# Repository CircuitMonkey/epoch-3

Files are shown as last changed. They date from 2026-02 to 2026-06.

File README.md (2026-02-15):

# epoch-3
Haptic Field Emitter using Vibration Motors

A follow on to [Epoch 2](https://github.com/CircuitMonkey/epoch-2) but in it's fifth generation.  Redesigned with [RaspberryPi Pico 2](https://www.raspberrypi.com/products/raspberry-pi-pico-2/) and a [4-inch TFT SPI resistive touch display](https://www.amazon.com/dp/B0CKRJ81B5).  Motors driven with [pca9685 PWM controller](https://learn.adafruit.com/adafruit-16-channel-pwm-servo-hat-for-raspberry-pi)/[Amazon PCA9685 Board](https://www.amazon.com/dp/B0D73811V8) and FET outputs in order to drive bigger motors. 

### Now 100% Python Free
Epoch-3 improves upon Epoch-2 by eliminating the use of Circuit Python, which ran extremely slow, cumbersome to program (no proper IDE) and caused many unexpected run-time errors. Epoch-3 uses proven Arduino C++ libraries and much easier to program/debug in for us old timers.

### Display Changes
The display has also been changed.  Epoch-2 used a IPS type display, and while it had more color rannge, it used nealy all the pins on the microcontroller and had slow update rates for most UI features. Simple things like the touch slider UI element were frustrating to use because of the slow reaction time. Epoch-3 uses a SPI type TFT display. While color range reminds us of those VGA days, the update rate is far faster.  

### Raspberry Pi Pico 2
For me, RaspberryPi Pico 2 has been a wonderful platform to develop with in other projects, especially when programming in Arduino.

### Ten Output Channels
This design outputs ten motor channels via 1/8-inch TRS jacks.  We elmininated the air pressure sensor input found on Epoch-2 as it was cumbersome to experiment with and yielded less than expected results.

### Refined User Interface
Epoch-2 had a much improved user interface over Epoch-1 and we will bring the best of those features into Epoch-3.  We hope to improve on that interface by adding more modes or at least a way to remember and review usage patterns.

## What is a "Haptic Field Emmiter" ?
The term haptic Field Emmiter is our cheeky term for Vibrator Controller.  This device is designed to drive up to ten vibration motors and intended for intimate bedroom use, usually by a solo male user.  The motors are embodied by a selection of attachments for specific zones of the male anatomy.  First, Epoch uses movable/removable rings, each with two small motors that attach on the male member. This edition will support up to three. Second, a similar, but different sized, ring is intented to be attached at the base of the member or around the testes. Again, containing two small motors.  Third, a common prostate massager toy (optional) has been selected and modified to work with epoch, also with two motors.  This "mesh" of motors forms the Haptic Field while in operation.  The Epoch device operates the motors in patterns to create the sensation of motion touching or stroking along a path.  Those patterns are controllable by sliders on the UI touch screen during use.  The UI can effect the intensiy of each motor group as well as the speed at which the patterns occur, offering a seemingly infinite palette of sensations over the time of use. The motors are of much-much lower intensity than common toys. They are for creating sensations and that's what leads to hours long euphoric sessions of use. This device is intended to get you into a grey zone of pleasure and keep you there.

## Clear Your Schedule
The designer has found that this device, when used properly, can lead to multiple-hours-long sessions of euphoric use.  Final orgasm is usually only the result of euphoria-fatigue or getting tired of using the device (or maybe finally your DoorDash showed up?). That said, the entire erogenous zone has a very short-fuse after that amount of time. Every inch of skin becomes a highly sensitive trigger point that is reactive to any novel sensations. Beware.

## For Research Purposes Only
Even in this fifth generation of careful design considerations, this device is experimental. It's not a solution for any known problem in the world and may not work for most users. It's also not for sale.  The design files are here for anyone who wants to try building one for themselves but you'll need enough skills to build all the components. Those skill include PCB assemly, 3D printing, silicone molding and other craft skills.  No kind of safety testing has been performed. Don't attach things onto or in your body if you don't understand the risks.

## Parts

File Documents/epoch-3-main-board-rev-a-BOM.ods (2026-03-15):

Epoch 3 BOM – Rev.A (2026-02)
Reference | Qty | Value | DNP | Have | Footprint | Datasheet
BAT1 | 1 | JST-PH |  |  | Connector_JST:JST_PH_S2B-PH-K_1x02_P2.00mm_Horizontal | ~
C1, C2 | 2 | 4.7uF/16V |  |  | Capacitor_SMD:C_0603_1608Metric | ~
C3 | 1 | 0.01uF |  |  | Capacitor_SMD:C_0603_1608Metric | ~
C4, C5, C6, C7, C8 | 5 | 22uF/16V |  |  | Capacitor_SMD:C_1812_4532Metric | ~
D1 | 1 | YEL |  |  | LED_SMD:LED_0603_1608Metric | ~
D2 | 1 | BLU |  |  | LED_SMD:LED_0603_1608Metric | ~
D3, D4, D5, D6, D7, D8, D9, D10, D11, D12 | 10 | NRVA4007T3G |  |  | Diode_SMD:D_SMA | http://www.onsemi.com/pub_link/Collateral/MRA4003T3-D.PDF
F1, F2, F3, F4, F5 | 5 | MF-MSMF075 |  |  | Resistor_SMD:R_1812_4532Metric | ~
J1, J2, J3, J4, J5 | 5 | AudioJack |  |  | CM_Connector_Audio:Jack_3.5mm_TRS_Tayda A-4780-Horizontal | ~
J6 | 1 | Conn_01x14 |  |  | CM_Connector_Header:SolderPads_1x14_P2.54mm_SMT | ~
J7 | 1 | Conn_01x03 | DNP |  | Connector_PinHeader_2.54mm:PinHeader_1x03_P2.54mm_Vertical | ~
JP1 | 1 | SolderJumper | DNP |  | Jumper:SolderJumper-2_P1.3mm_Open_TrianglePad1.0x1.5mm | ~
Q1, Q2, Q3, Q4, Q5, Q6, Q7, Q8, Q9, Q10 | 10 | Si1308EDL |  |  | Package_TO_SOT_SMD:SOT-323_SC-70 | https://www.vishay.com/docs/63399/si1308edl.pdf
Q11, Q12 | 2 | DMG2305 |  |  | CM_Chip_Packages:SOT-23 | https://www.diodes.com/datasheet/download/DMG2305UX.pdf
Q13 | 1 | BC846-SOT23 |  |  | CM_Chip_Packages:SOT-23 | https://assets.nexperia.com/documents/data-sheet/BC846_SER.pdf
R1, R2, R3, R4, R5, R6, R7, R31, R32, R35, R39 | 11 | 1K |  |  | Resistor_SMD:R_0603_1608Metric | ~
R8, R9, R13, R14, R15, R16, R17, R18, R19, R20 | 10 | 100R |  |  | Resistor_SMD:R_0603_1608Metric | ~
R10 | 1 | 2K |  |  | Resistor_SMD:R_0603_1608Metric | ~
R11 | 1 | 330R |  |  | Resistor_SMD:R_0603_1608Metric | ~
R12 | 1 | 220R |  |  | Resistor_SMD:R_0603_1608Metric | ~
R21, R22, R23, R24, R25, R26, R27, R28, R29, R30, R33, R34, R36, R40 | 14 | 100K |  |  | Resistor_SMD:R_0603_1608Metric | ~
R37, R38 | 2 | 4.7K |  |  | Resistor_SMD:R_0603_1608Metric | ~
SW1 | 1 | Side-Slide |  |  | CM_Switches:SameSky-Slide-8x4mm-SPDT-THD | https://www.sameskydevices.com/product/resource/slw-864587-2a-ra-n-d.pdf
U1 | 1 | Pico2-RP2350 |  |  | CM_Chip_Packages:RaspberryPi-Pico2 | https://www.raspberrypi.com/products/raspberry-pi-pico-2/
U2 | 1 | MCP73831T-2ACI/OT |  |  | Package_TO_SOT_SMD:SOT-23-5 | http://ww1.microchip.com/downloads/en/DeviceDoc/20001984g.pdf
U3 | 1 | PCA9685PW |  |  | Package_SO:TSSOP-28_4.4x9.7mm_P0.65mm | http://www.nxp.com/docs/en/data-sheet/PCA9685.pdf

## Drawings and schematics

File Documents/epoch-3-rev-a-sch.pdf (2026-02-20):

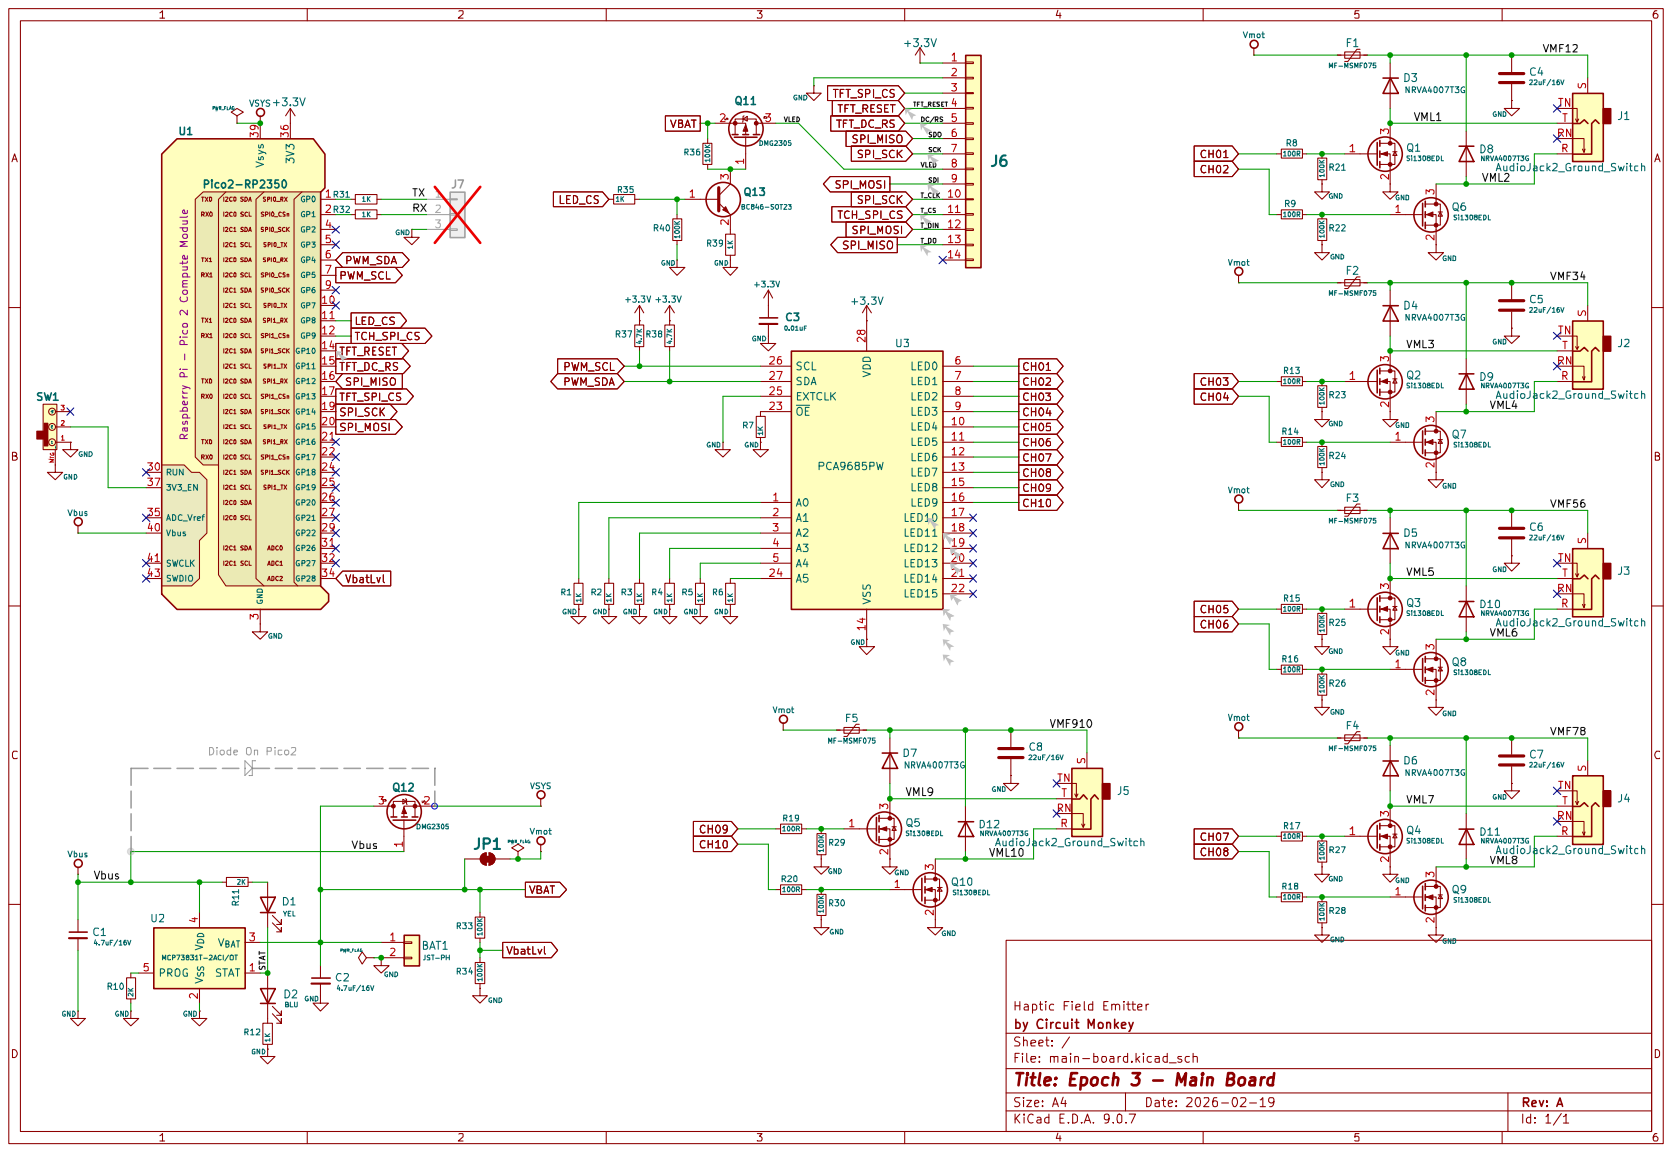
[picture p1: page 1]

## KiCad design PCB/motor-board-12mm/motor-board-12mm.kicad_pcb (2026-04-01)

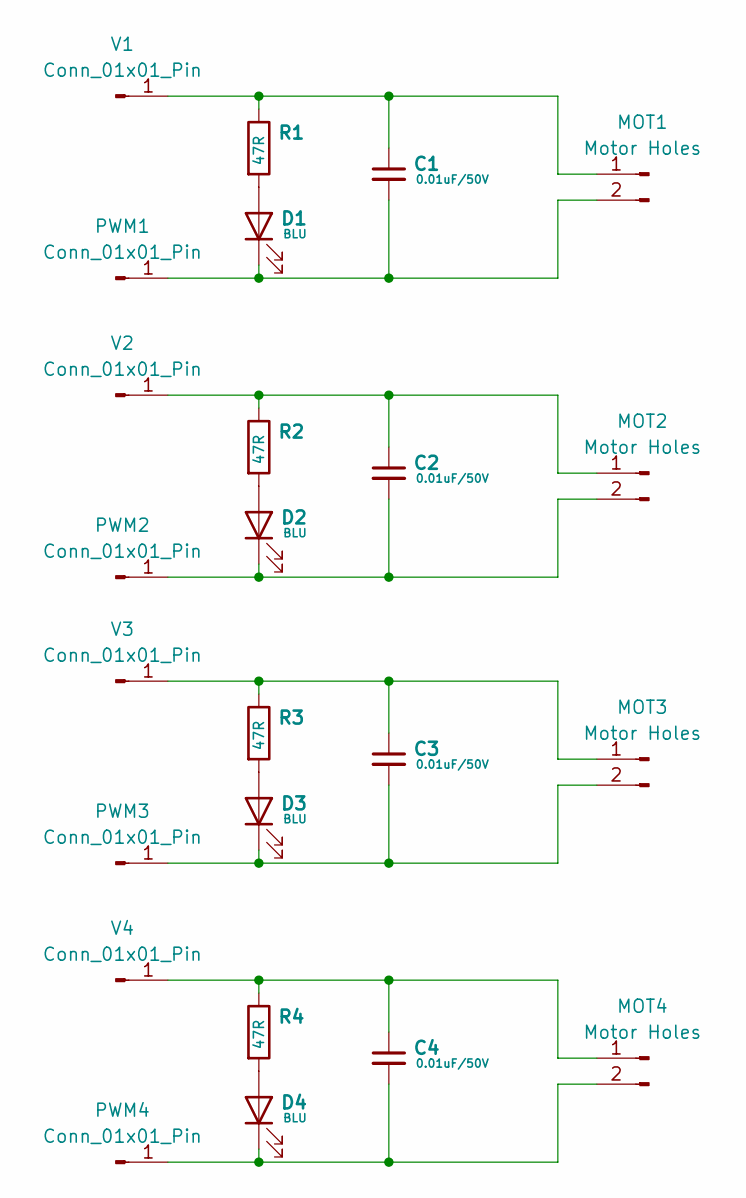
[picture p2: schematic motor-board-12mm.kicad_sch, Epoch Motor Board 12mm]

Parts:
C1, C2, C3, C4: 0.01uF/50V; C_0603_1608Metric
D1, D2, D3, D4: BLU; LED_0603_1608Metric
MOT1, MOT2, MOT3, MOT4: Motor Holes; Motor-PCB
PWM1, PWM2, PWM3, PWM4: Conn_01x01_Pin; TestPoint_Pad_D2.0mm
R1, R2, R3, R4: 47R; R_0603_1608Metric
V1, V2, V3, V4: Conn_01x01_Pin; TestPoint_Pad_2.0x2.0mm

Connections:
unnamed: D1.2 (A), R1.2
unnamed: C1.2, D1.1 (K), MOT1.2, PWM1.1
unnamed: D2.2 (A), R2.2
unnamed: C2.2, D2.1 (K), MOT2.2, PWM2.1
unnamed: D3.2 (A), R3.2
unnamed: C3.2, D3.1 (K), MOT3.2, PWM3.1
unnamed: D4.2 (A), R4.2
unnamed: C4.2, D4.1 (K), MOT4.2, PWM4.1
unnamed: C1.1, MOT1.1, R1.1, V1.1
unnamed: C2.1, MOT2.1, R2.1, V2.1
unnamed: C3.1, MOT3.1, R3.1, V3.1
unnamed: C4.1, MOT4.1, R4.1, V4.1

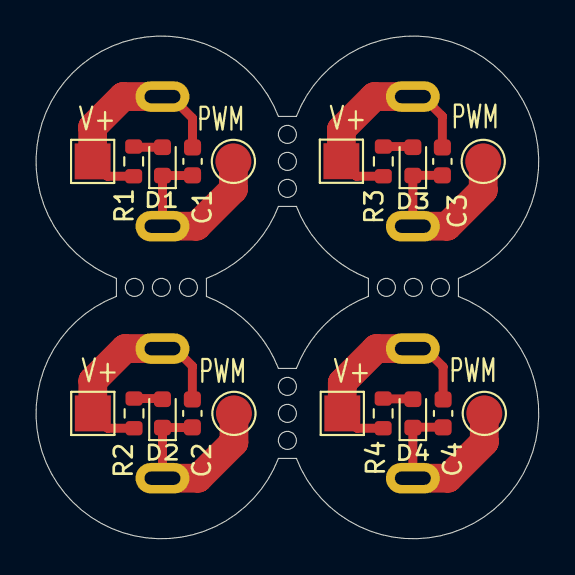
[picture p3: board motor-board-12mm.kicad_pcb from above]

Board: 2 copper layers, 27.9 x 27.9 mm, 24 parts (0 on the bottom side), 12 nets.

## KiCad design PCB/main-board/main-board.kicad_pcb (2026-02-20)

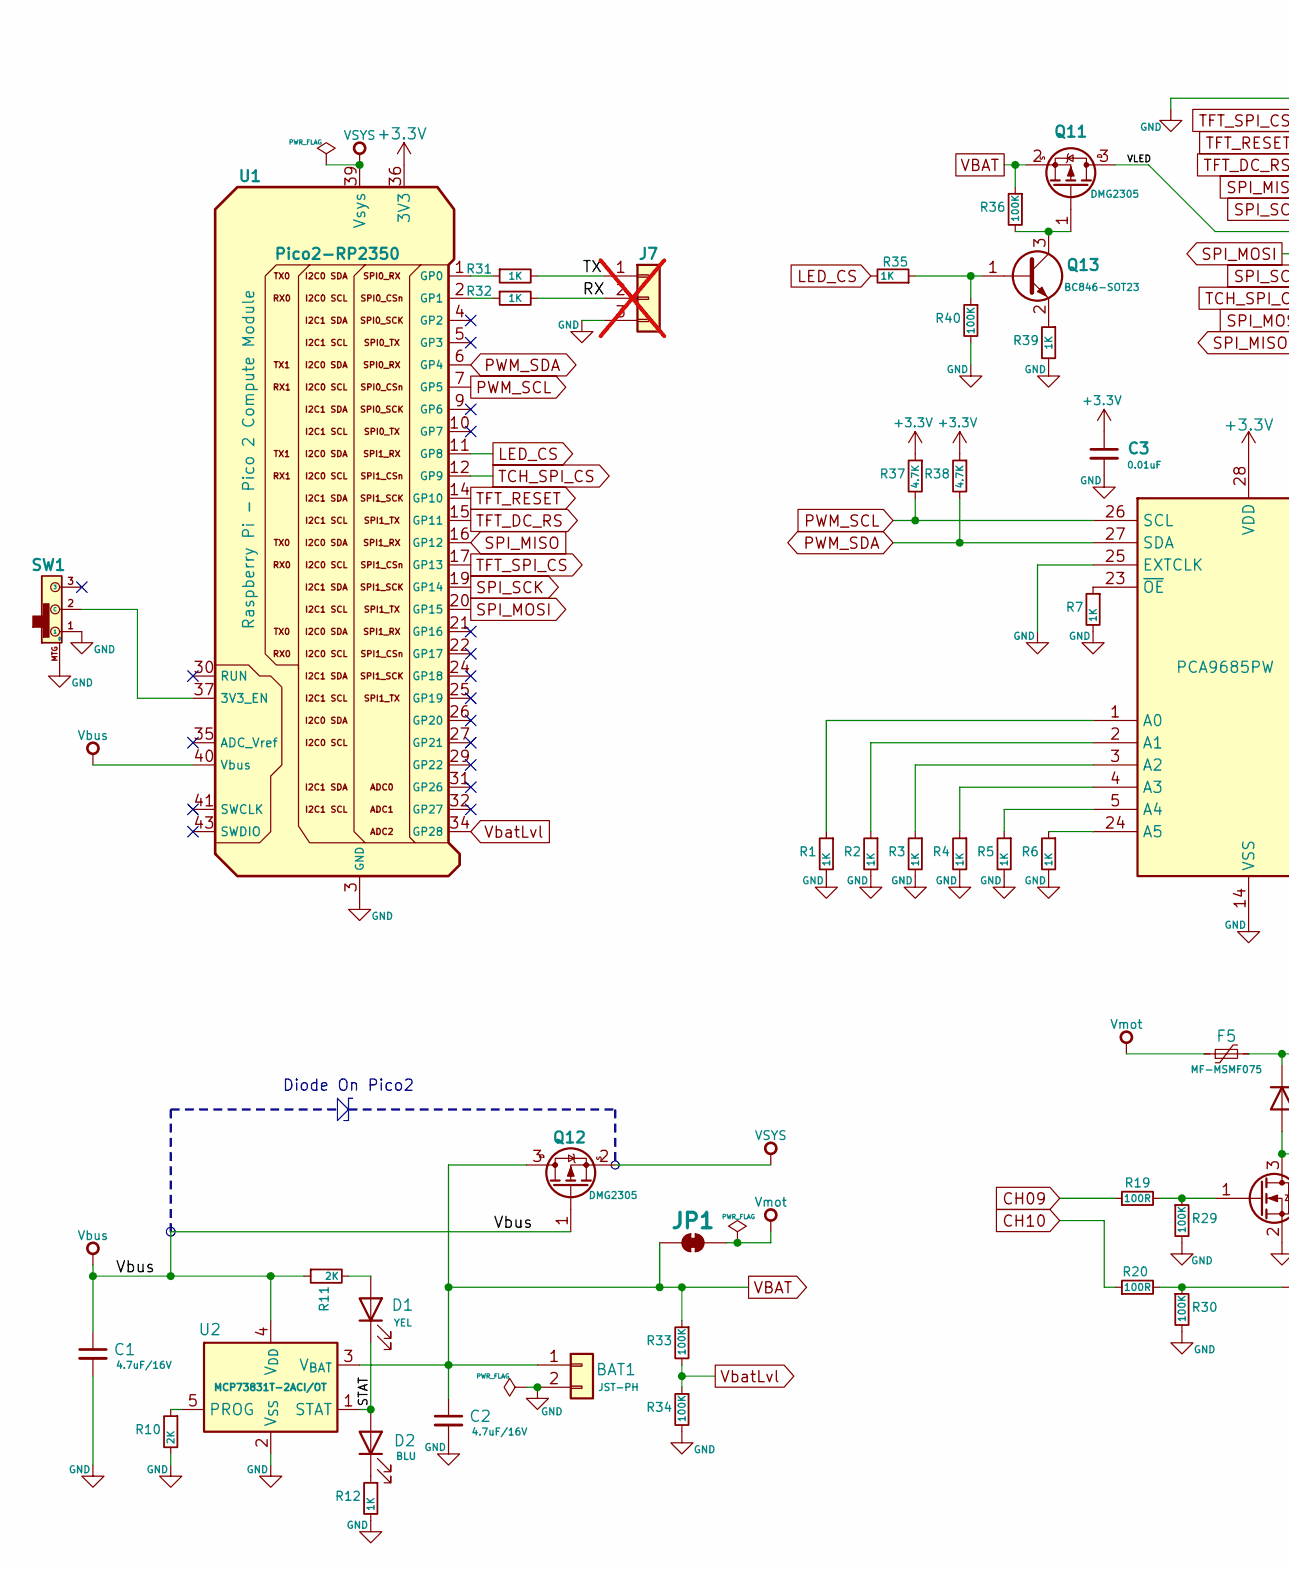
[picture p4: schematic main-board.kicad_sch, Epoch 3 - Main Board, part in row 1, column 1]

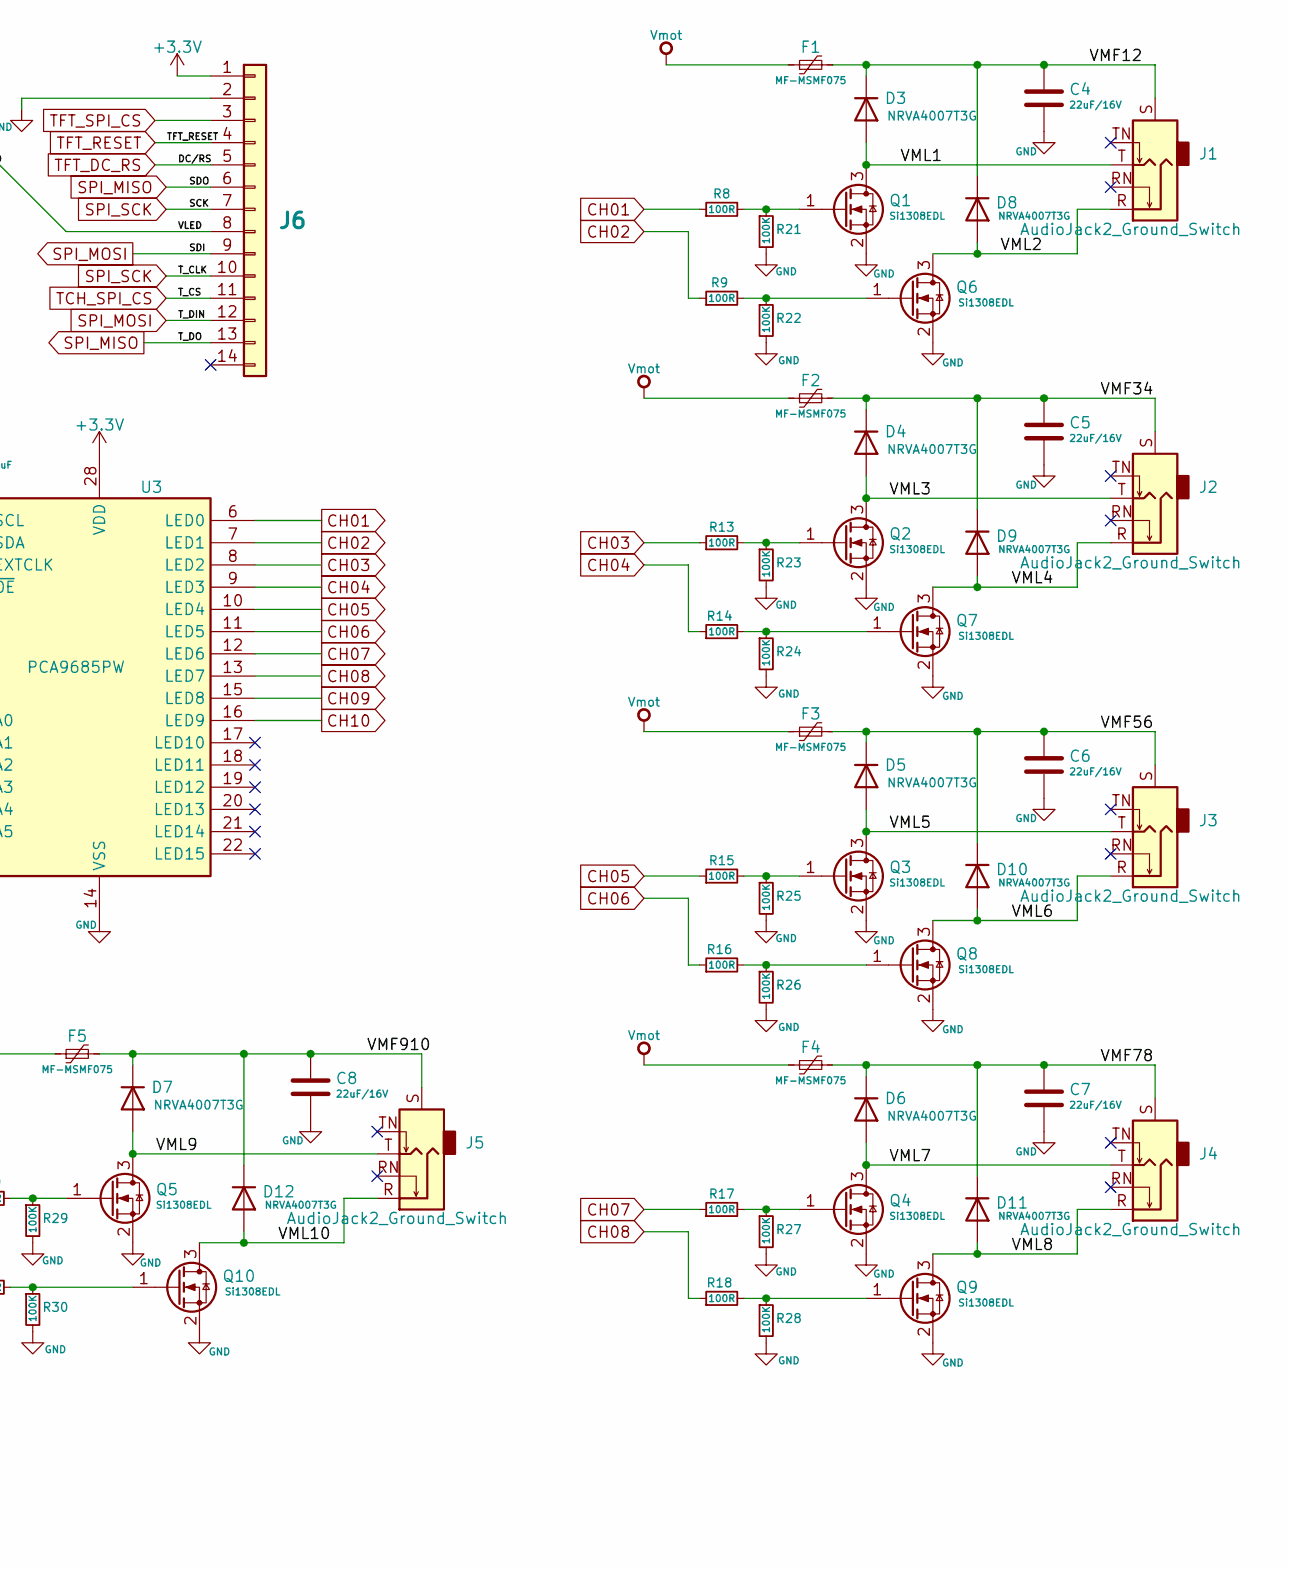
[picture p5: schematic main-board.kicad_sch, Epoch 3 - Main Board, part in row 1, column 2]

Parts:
BAT1: JST-PH; JST_PH_S2B-PH-K_1x02_P2.00mm_Horizontal
C1, C2: 4.7uF/16V; C_0603_1608Metric
C3: 0.01uF; C_0603_1608Metric
C4, C5, C6, C7, C8: 22uF/16V; C_1812_4532Metric
D1: YEL; LED_0603_1608Metric
D2: BLU; LED_0603_1608Metric
D3, D4, D5, D6, D7, D8, D9, D10, D11, D12: NRVA4007T3G; D_SMA
F1, F2, F3, F4, F5: MF-MSMF075; R_1812_4532Metric
J1, J2, J3, J4, J5: AudioJack2_Ground_Switch; Jack_3.5mm_TRS_Tayda A-4780-Horizontal
J6: Conn_01x14; SolderPads_1x14_P2.54mm_SMT
J7: Conn_01x03; PinHeader_1x03_P2.54mm_Vertical; not fitted
JP1: SolderJumper_2_Bridged; SolderJumper-2_P1.3mm_Open_TrianglePad1.0x1.5mm
Q1, Q2, Q3, Q4, Q5, Q6, Q7, Q8, Q9, Q10: Si1308EDL; SOT-323_SC-70
Q11, Q12: DMG2305; SOT-23; MPN DMG2305UX
Q13: BC846-SOT23; SOT-23
R1, R2, R3, R4, R5, R6, R7, R12, R31, R32, R35, R39: 1K; R_0603_1608Metric
R8, R9, R13, R14, R15, R16, R17, R18, R19, R20: 100R; R_0603_1608Metric
R10, R11: 2K; R_0603_1608Metric
R21, R22, R23, R24, R25, R26, R27, R28, R29, R30, R33, R34, R36, R40: 100K; R_0603_1608Metric
R37, R38: 4.7K; R_0603_1608Metric
SW1: SameSky-Side-Slide; SameSky-Slide-8x4mm-SPDT-THD; MPN SLW-864587-2A-RA-N-D
U1: Pico2-RP2350; RaspberryPi-Pico2
U2: MCP73831T-2ACI/OT; SOT-23-5
U3: PCA9685PW; TSSOP-28_4.4x9.7mm_P0.65mm

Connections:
+3.3V: C3.1, J6.1, R37.1, R38.1, U1.36 (3V3), U3.28 (VDD)
/RX: J7.2, R32.2
/STAT: D1.1 (K), D2.2 (A), U2.1 (STAT)
/TX: J7.1, R31.2
/VLED: J6.8, Q11.3 (S)
/VMF12: C4.1, D3.1 (K), D8.1 (K), F1.2, J1.S
/VMF34: C5.1, D4.1 (K), D9.1 (K), F2.2, J2.S
/VMF56: C6.1, D5.1 (K), D10.1 (K), F3.2, J3.S
/VMF78: C7.1, D6.1 (K), D11.1 (K), F4.2, J4.S
/VMF910: C8.1, D7.1 (K), D12.1 (K), F5.2, J5.S
/VML1: D3.2 (A), J1.T, Q1.3 (D)
/VML2: D8.2 (A), J1.R, Q6.3 (D)
/VML3: D4.2 (A), J2.T, Q2.3 (D)
/VML4: D9.2 (A), J2.R, Q7.3 (D)
/VML5: D5.2 (A), J3.T, Q3.3 (D)
/VML6: D10.2 (A), J3.R, Q8.3 (D)
/VML7: D6.2 (A), J4.T, Q4.3 (D)
/VML8: D11.2 (A), J4.R, Q9.3 (D)
/VML9: D7.2 (A), J5.T, Q5.3 (D)
/VML10: D12.2 (A), J5.R, Q10.3 (D)
CH01: R8.1, U3.6 (LED0)
CH02: R9.1, U3.7 (LED1)
CH03: R13.1, U3.8 (LED2)
CH04: R14.1, U3.9 (LED3)
CH05: R15.1, U3.10 (LED4)
CH06: R16.1, U3.11 (LED5)
CH07: R17.1, U3.12 (LED6)
CH08: R18.1, U3.13 (LED7)
CH09: R19.1, U3.15 (LED8)
CH10: R20.1, U3.16 (LED9)
GND: BAT1.2, C1.2, C2.2, C3.2, C4.2, C5.2, C6.2, C7.2, C8.2, J6.2, J7.3, Q1.2 (S), Q2.2 (S), Q3.2 (S), Q4.2 (S), Q5.2 (S), Q6.2 (S), Q7.2 (S), Q8.2 (S), Q9.2 (S), Q10.2 (S), R1.2, R2.2, R3.2, R4.2, R5.2, R6.2, R7.2, R10.2, R12.2, R21.2, R22.2, R23.2, R24.2, R25.2, R26.2, R27.2, R28.2, R29.2, R30.2, R34.2, R39.2, R40.2, SW1.1, SW1.MTG (MTG1), SW1.MTG2, U1.3 (GND), U1.8 (GND), U1.13 (GND), U1.18 (GND), U1.23 (GND), U1.28 (GND), U1.33 (GND), U1.38 (GND), U1.42 (GND), U2.2 (V_{SS}), U3.14 (VSS), U3.25 (EXTCLK)
LED_CS: R35.2, U1.11 (GP8)
unnamed: D1.2 (A), R11.2
unnamed: D2.1 (K), R12.1
unnamed: Q1.1 (G), R8.2, R21.1
unnamed: Q2.1 (G), R13.2, R23.1
unnamed: Q3.1 (G), R15.2, R25.1
unnamed: Q4.1 (G), R17.2, R27.1
unnamed: Q5.1 (G), R19.2, R29.1
unnamed: Q6.1 (G), R9.2, R22.1
unnamed: Q7.1 (G), R14.2, R24.1
unnamed: Q8.1 (G), R16.2, R26.1
unnamed: Q9.1 (G), R18.2, R28.1
unnamed: Q10.1 (G), R20.2, R30.1
unnamed: Q11.1 (G), Q13.3 (C), R36.2
unnamed: Q13.1 (B), R35.1, R40.1
unnamed: Q13.2 (E), R39.1
unnamed: SW1.2 (C), U1.37 (3V3_EN)
unnamed: R31.1, U1.1 (GP0)
unnamed: R32.1, U1.2 (GP1)
unnamed: R10.1, U2.5 (PROG)
unnamed: R1.1, U3.1 (A0)
unnamed: R2.1, U3.2 (A1)
unnamed: R3.1, U3.3 (A2)
unnamed: R4.1, U3.4 (A3)
unnamed: R5.1, U3.5 (A4)
unnamed: R6.1, U3.24 (A5)
unnamed: R7.1, U3.23 (~OE)
PWM_SCL: R37.2, U1.7 (GP5), U3.26 (SCL)
PWM_SDA: R38.2, U1.6 (GP4), U3.27 (SDA)
SPI_MISO: J6.6, J6.13, U1.16 (GP12)
SPI_MOSI: J6.9, J6.12, U1.20 (GP15)
SPI_SCK: J6.7, J6.10, U1.19 (GP14)
TCH_SPI_CS: J6.11, U1.12 (GP9)
TFT_DC_RS: J6.5, U1.15 (GP11)
TFT_RESET: J6.4, U1.14 (GP10)
TFT_SPI_CS: J6.3, U1.17 (GP13)
VBAT: BAT1.1, C2.1, JP1.1 (A), Q11.2 (D), Q12.3 (S), R33.1, R36.1, U2.3 (V_{BAT})
VSYS: Q12.2 (D), U1.39 (Vsys)
VbatLvl: R33.2, R34.1, U1.34 (GP28)
Vbus: C1.1, Q12.1 (G), R11.1, U1.40 (Vbus), U2.4 (V_{DD})
Vmot: F1.1, F2.1, F3.1, F4.1, F5.1, JP1.2 (B)

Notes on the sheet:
Diode On Pico2

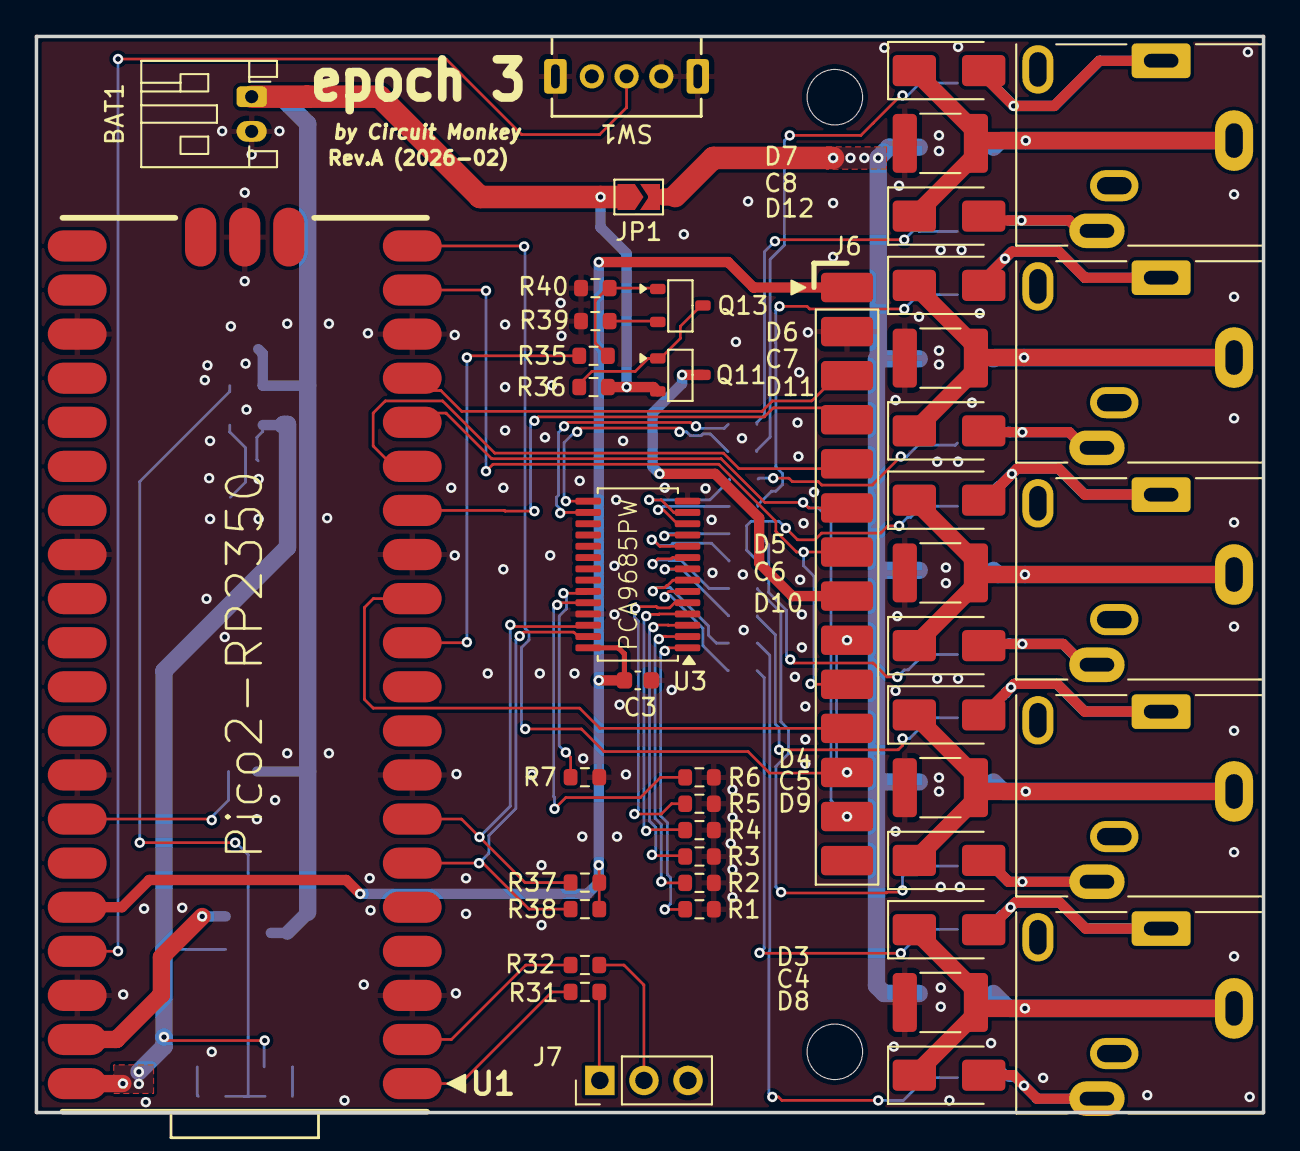
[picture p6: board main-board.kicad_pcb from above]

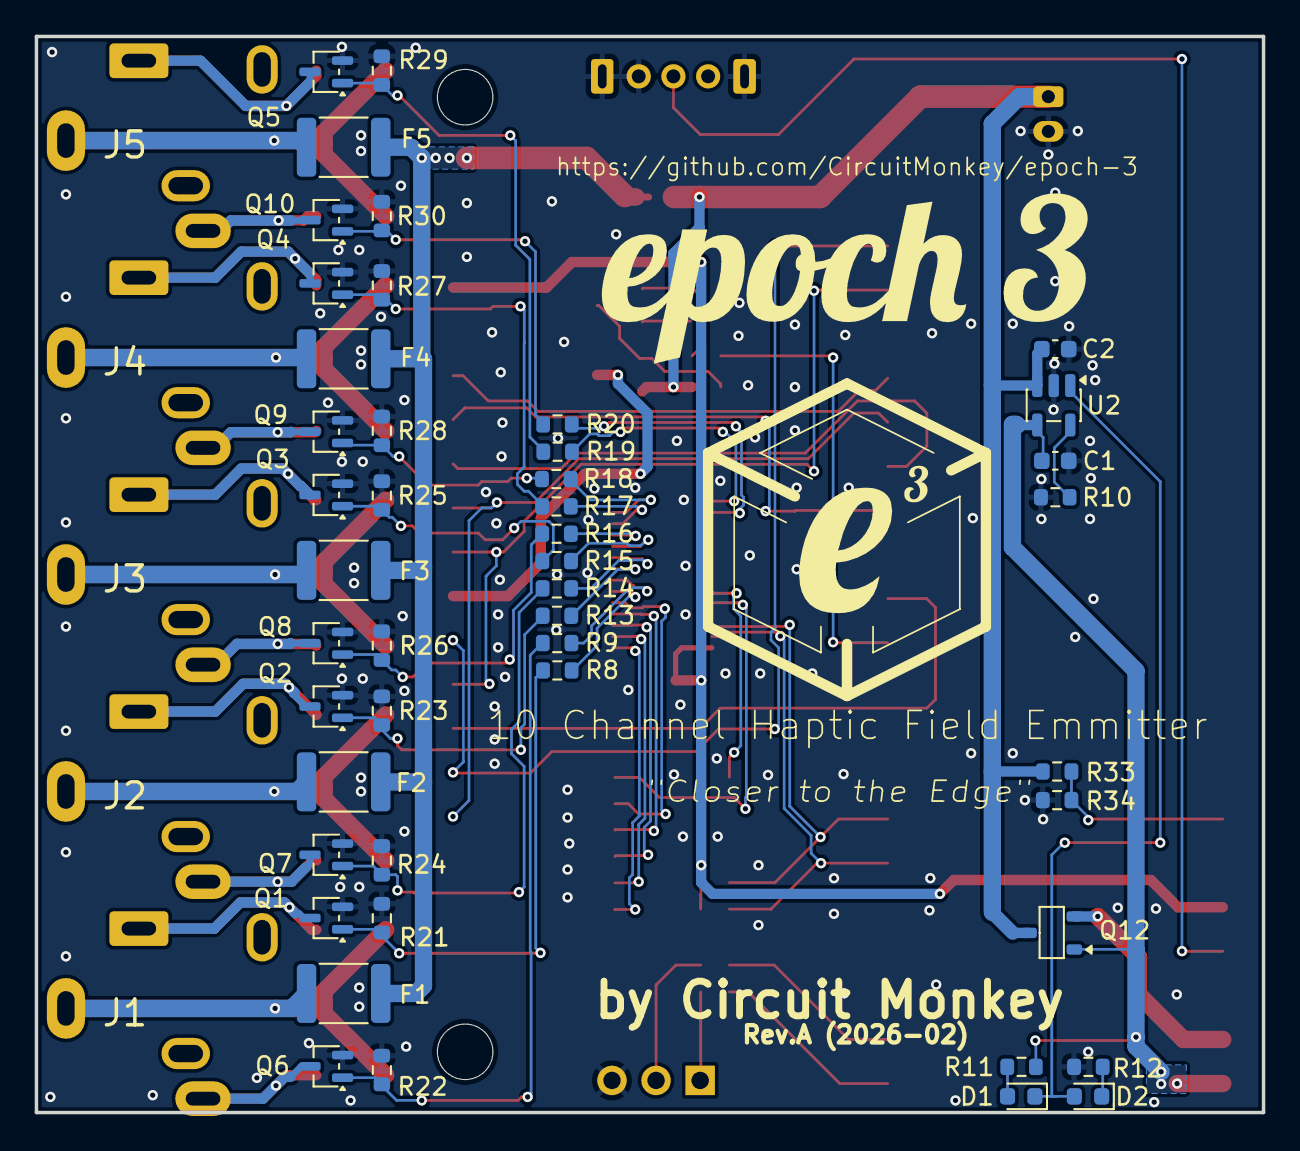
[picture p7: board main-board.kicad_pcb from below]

Board: 2 copper layers, 70.7 x 62.0 mm, 91 parts (46 on the bottom side), 72 nets.

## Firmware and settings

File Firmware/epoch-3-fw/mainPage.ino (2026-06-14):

#include <TFT_eWidget.h>  // Widget library

#define SLIDER_Y 190
#define SLIDER_1_X 12
#define SLIDER_H 180
#define SLIDER_SPACING 60
#define SLIDER_KNOB_CORNER 10
#define SLIDER_OUTER_CORNER 14

#define THEME_COLOR_LITE 0xB0DF
#define THEME_COLOR_MID 0x8133
#define THEME_COLOR_DARK 0x3868

#define BUTTON_SM_SIZE 64
#define BUTTON_LG_SIZE 96
#define GLYPH_SM_SIZE 24

#define MODE_UP_DOWN 0
#define MODE_DOWN 1
#define MODE_UP 2
#define MODE_RANDOM 3
#define MODE_DOT_UP_DOWN 4
#define MODE_DOT_DOWN 5
#define MODE_DOT_UP 6
#define MODE_AST 7

#define MODE_ROW_1_Y 12
#define MODE_ROW_2_Y 88
#define MODE_COL_1_X 12
#define MODE_COL_2_X 88
#define MODE_COL_3_X 164
#define MODE_COL_4_X 240

#define PLAY_PAUSE_X 12
#define PLAY_PAUSE_Y 382

#define HAMMER_X 250
#define HAMMER_Y 400
#define TRIM_X 184


TFT_eSprite knob = TFT_eSprite(&tft);         // Sprite for the slide knob
SliderWidget s1 = SliderWidget(&tft, &knob);  // Slider 1 widget
SliderWidget s2 = SliderWidget(&tft, &knob);  // Slider 2 widget
SliderWidget s3 = SliderWidget(&tft, &knob);  // Slider 3 widget
SliderWidget s4 = SliderWidget(&tft, &knob);  // Slider 4 widget
SliderWidget s5 = SliderWidget(&tft, &knob);  // Slider 5 widget

uint8_t sliderValue[][5] = {
  { 30,50,50,30,60 }, // Up-down
  { 30,50,50,30,60 }, // down
  { 30,50,50,30,60 }, // up
  { 30,50,50,30,60 }, // random
  { 30,50,50,30,60 }, // dot up-down
  { 30,50,50,30,60 }, // dot down
  { 30,50,50,30,60 }, // dot up
  { 30,50,50,30,60 }, // asterisk
};

uint8_t mode = MODE_UP_DOWN;
uint8_t run = 0;
boolean drag = false;
boolean hammerTime = false;
boolean trimTime = false;

void mainPageInit() {
  // Slider slot parameters
  slider_t param;
  tft.fillScreen(TFT_BLACK);

  updateModeButtons();

  // Create slider using parameters and plot at 0,0
  param.slotWidth = 12;                // Note: ends of slot will be rounded and anti-aliased
  param.slotLength = SLIDER_H;         // Length includes rounded ends
  param.slotColor = THEME_COLOR_DARK;  // Slot color
  param.slotBgColor = TFT_BLACK;       // Slot background color for anti-aliasing
  param.orientation = V_SLIDER;        // sets it "true" for horizontal

  // Slider control knob parameters (smooth rounded rectangle)
  param.knobWidth = 45;                    // Always along x axis
  param.knobHeight = 35;                   // Always along y axis
  param.knobRadius = SLIDER_KNOB_CORNER;   // Corner radius
  param.knobColor = THEME_COLOR_LITE;      // Anti-aliased with slot backgound colour
  param.knobLineColor = THEME_COLOR_DARK;  // Colour of marker line (set to same as knobColor for no line)

  // Slider range and movement speed
  param.sliderLT = 99;      // Left side for horizontal, top for vertical slider
  param.sliderRB = 0;        // Right side for horizontal, bottom for vertical slider
  param.startPosition = 50;  // Start position for control knob
  param.sliderDelay = 100;   // Microseconds per pixel movement delay (0 = no delay)

  int16_t x, y;   // x and y can be negative
  uint16_t w, h;  // Width and height

  drawSmallGlyph(SLIDER_1_X, SLIDER_Y - 26, tip);
  drawSmallGlyph(1 * SLIDER_SPACING + SLIDER_1_X, SLIDER_Y - 26, mid);
  drawSmallGlyph(2 * SLIDER_SPACING + SLIDER_1_X, SLIDER_Y - 26, plug);
  drawSmallGlyph(3 * SLIDER_SPACING + SLIDER_1_X, SLIDER_Y - 26, snail);
  drawSmallGlyph(4 * SLIDER_SPACING + SLIDER_1_X, SLIDER_Y - 26, ghost);

  s1.drawSlider(SLIDER_1_X, SLIDER_Y, param);
  s1.getBoundingRect(&x, &y, &w, &h);                                    // Update x,y,w,h with bounding box
  tft.drawRoundRect(x, y, w, h, SLIDER_OUTER_CORNER, THEME_COLOR_LITE);  // Draw rectangle outline

  s2.drawSlider(1 * SLIDER_SPACING + SLIDER_1_X, SLIDER_Y, param);
  s2.getBoundingRect(&x, &y, &w, &h);
  tft.drawRoundRect(x, y, w, h, SLIDER_OUTER_CORNER, THEME_COLOR_LITE);

  s3.drawSlider(2 * SLIDER_SPACING + SLIDER_1_X, SLIDER_Y, param);
  s3.getBoundingRect(&x, &y, &w, &h);
  tft.drawRoundRect(x, y, w, h, SLIDER_OUTER_CORNER, THEME_COLOR_LITE);

  s4.drawSlider(3 * SLIDER_SPACING + SLIDER_1_X, SLIDER_Y, param);
  s4.getBoundingRect(&x, &y, &w, &h);
  tft.drawRoundRect(x, y, w, h, SLIDER_OUTER_CORNER, THEME_COLOR_LITE);

  s5.drawSlider(4 * SLIDER_SPACING + SLIDER_1_X, SLIDER_Y, param);
  s5.getBoundingRect(&x, &y, &w, &h);
  tft.drawRoundRect(x, y, w, h, SLIDER_OUTER_CORNER, THEME_COLOR_LITE);

  updateSliderPositions();
  pwmInitMode(mode);

  // PLay/Pause toggle button
  updatePlayPauseButton();

  updateHammerButton();
  updateTrimButton();
}

void mainPageLoop() {
  static uint32_t scanTime = millis();
  uint16_t t_x = 9999, t_y = 9999;  // To store the touch coordinates

  // Scan for touch every 50ms
  if (millis() - scanTime >= 20) {
    if (tft.getTouch(&t_x, &t_y, 250)) {
      if (s1.checkTouch(t_x, t_y)) {
        Serial.print("Slider 1 = ");
        Serial.println(s1.getSliderPosition());
        sliderValue[mode][0] = s1.getSliderPosition();
      }
      if (s2.checkTouch(t_x, t_y)) {
        Serial.print("Slider 2 = ");
        Serial.println(s2.getSliderPosition());
        sliderValue[mode][1] = s2.getSliderPosition();
      }
      if (s3.checkTouch(t_x, t_y)) {
        Serial.print("Slider 3 = ");
        Serial.println(s3.getSliderPosition());
        sliderValue[mode][2] = s3.getSliderPosition();
      }
      if (s4.checkTouch(t_x, t_y)) {
        Serial.print("Slider 4 = ");
        Serial.println(s4.getSliderPosition());
        sliderValue[mode][3] = s4.getSliderPosition();
      }
      if (s5.checkTouch(t_x, t_y)) {
        Serial.print("Slider 5 = ");
        Serial.println(s5.getSliderPosition());
        sliderValue[mode][4] = s5.getSliderPosition();
      }

      // Mode selection
      if (modeSelectTouch(t_x, t_y)) {
        updateModeButtons();
      }

      // Play/Pause toggle
      if (!drag && playPauseSelectTouch(t_x, t_y)) {
        if (run) {
          run = 0;
        } else {
          run = 1;
        }
        updatePlayPauseButton();
      }

      // Hammer Time toggle
      if (!drag && isSmallTouched(t_x, t_y, HAMMER_X, HAMMER_Y)) {
        if (hammerTime) {
          hammerTime = false;
        } else {
          hammerTime = true;
        }
        updateHammerButton();
      }
      // Trim Time toggle
      if (!drag && isSmallTouched(t_x, t_y, TRIM_X, HAMMER_Y)) {
//        if (trimTime) {
//          trimTime = false;
//        } else {
//          trimTime = true;
//        }
        trimTime = !trimTime;

        updateTrimButton();
      }

      drag = true;
    } else {
      drag = false;
    }

    scanTime = millis();
  }
}

void drawSmallGlyph(uint16_t x, uint16_t y, const unsigned char *glyph) {
  TFT_eSprite gspr = TFT_eSprite(&tft);
  gspr.fillScreen(TFT_BLACK);
  gspr.setColorDepth(1);
  gspr.createSprite(24, 24);
  gspr.setBitmapColor(THEME_COLOR_MID, TFT_BLACK);
  gspr.pushImage(0, 0, 24, 24, (uint16_t *)glyph);
  gspr.pushSprite(x + 12, y);
}

void drawSmallButton(uint16_t x, uint16_t y, uint16_t color, const unsigned char *glyph) {
  TFT_eSprite sspr = TFT_eSprite(&tft);  // Declare Sprite with pointer to "tft" object
  sspr.fillScreen(TFT_BLACK);
  sspr.setColorDepth(1);
  sspr.createSprite(64, 64);
  sspr.setBitmapColor(color, TFT_BLACK);
  sspr.pushImage(0, 0, 64, 64, (uint16_t *)glyph);
  sspr.pushSprite(x, y);
}

void drawLargeButton(uint16_t x, uint16_t y, const unsigned char *glyph) {
  TFT_eSprite bspr = TFT_eSprite(&tft);  // Declare Sprite with pointer to "tft" object
  bspr.fillScreen(TFT_BLACK);
  bspr.setColorDepth(1);
  bspr.createSprite(96, 96);
  bspr.setBitmapColor(THEME_COLOR_MID, TFT_BLACK);
  bspr.pushImage(0, 0, 96, 96, (uint16_t *)glyph);
  bspr.pushSprite(x, y);
}

void updateModeButtons() {
    // Two rows of glyph buttons
    drawSmallButton(MODE_COL_1_X, MODE_ROW_1_Y, mode == MODE_UP_DOWN ? THEME_COLOR_LITE : THEME_COLOR_DARK, upDown);
    drawSmallButton(MODE_COL_2_X, MODE_ROW_1_Y, mode == MODE_DOWN ? THEME_COLOR_LITE : THEME_COLOR_DARK, down);
    drawSmallButton(MODE_COL_3_X, MODE_ROW_1_Y, mode == MODE_UP ? THEME_COLOR_LITE : THEME_COLOR_DARK, up);
    drawSmallButton(MODE_COL_4_X, MODE_ROW_1_Y, mode == MODE_RANDOM ? THEME_COLOR_LITE : THEME_COLOR_DARK, dice);

    drawSmallButton(MODE_COL_1_X, MODE_ROW_2_Y, mode == MODE_DOT_UP_DOWN ? THEME_COLOR_LITE : THEME_COLOR_DARK, dotUpDown);
    drawSmallButton(MODE_COL_2_X, MODE_ROW_2_Y, mode == MODE_DOT_DOWN ? THEME_COLOR_LITE : THEME_COLOR_DARK, dotDown);
    drawSmallButton(MODE_COL_3_X, MODE_ROW_2_Y, mode == MODE_DOT_UP ? THEME_COLOR_LITE : THEME_COLOR_DARK, dotUp);
    drawSmallButton(MODE_COL_4_X, MODE_ROW_2_Y, mode == MODE_AST ? THEME_COLOR_LITE : THEME_COLOR_DARK, asterisk);
}

void updatePlayPauseButton() {
  drawLargeButton(PLAY_PAUSE_X, PLAY_PAUSE_Y, run ? pause_glyph : play);
}

void updateHammerButton() {
  drawSmallButton(HAMMER_X, HAMMER_Y, hammerTime ? THEME_COLOR_LITE : THEME_COLOR_DARK, hammer);
}
void updateTrimButton() {
  drawSmallButton(TRIM_X, HAMMER_Y, trimTime ? THEME_COLOR_LITE : THEME_COLOR_DARK, trim);
}

/**
 * If one of the mode change buttons was pressed and is different than
 * the current mode, mode variable will be set to the pressed mode.
 *
 * @return true only if the mode was changed.
*/
boolean modeSelectTouch(uint16_t x, uint16_t y) {
  boolean changed = false;
  if (y > MODE_ROW_1_Y && y < MODE_ROW_1_Y + BUTTON_SM_SIZE) {
    if (x > MODE_COL_1_X && x < MODE_COL_1_X + BUTTON_SM_SIZE) {
      if (mode != 0) {
        mode = 0;
        changed = true;
      }
    } else if (x > MODE_COL_2_X && x < MODE_COL_2_X + BUTTON_SM_SIZE) {
      if (mode != 1) {
        mode = 1;
        changed = true;
      }
    } else if (x > MODE_COL_3_X && x < MODE_COL_3_X + BUTTON_SM_SIZE) {
      if (mode != 2) {
        mode = 2;
        changed = true;
      }
    } else if (x > MODE_COL_4_X && x < MODE_COL_4_X + BUTTON_SM_SIZE) {
      if (mode != 3) {
        mode = 3;
        changed = true;
      }
    }
  } else if (y > MODE_ROW_2_Y && y < MODE_ROW_2_Y + BUTTON_SM_SIZE) {
    if (x > MODE_COL_1_X && x < MODE_COL_1_X + BUTTON_SM_SIZE) {
      if (mode != 4) {
        mode = 4;
        changed = true;
      }
    } else if (x > MODE_COL_2_X && x < MODE_COL_2_X + BUTTON_SM_SIZE) {
      if (mode != 5) {
        mode = 5;
        changed = true;
      }
    } else if (x > MODE_COL_3_X && x < MODE_COL_3_X + BUTTON_SM_SIZE) {
      if (mode != 6) {
        mode = 6;
        changed = true;
      }
    } else if (x > MODE_COL_4_X && x < MODE_COL_4_X + BUTTON_SM_SIZE) {
      if (mode != 7) {
        mode = 7;
        changed = true;
      }
    }
  }

  if ( changed ) {
    updateSliderPositions();
    pwmInitMode(mode);
    Serial.printf("Mode Changed: %d\n", mode);
  }

  return changed;
}

boolean playPauseSelectTouch(uint16_t x, uint16_t y) {
  boolean changed = false;
  if (y > PLAY_PAUSE_Y && y < PLAY_PAUSE_Y + BUTTON_LG_SIZE) {
    if (x > PLAY_PAUSE_X && x < PLAY_PAUSE_X + BUTTON_LG_SIZE) {
      changed = true;
    }
  }
  return changed;
}

boolean hammerSelectTouch(uint16_t x, uint16_t y) {
  boolean changed = false;
  if (y > HAMMER_Y && y < HAMMER_Y + BUTTON_SM_SIZE) {
    if (x > HAMMER_X && x < HAMMER_X + BUTTON_SM_SIZE) {
      changed = true;
    }
  }
  return changed;
}
boolean isSmallTouched(uint16_t x, uint16_t y, uint16_t btnX, uint16_t btnY) {
  if (y > btnY && y < btnY + BUTTON_SM_SIZE) {
    if (x > btnX && x < btnX + BUTTON_SM_SIZE) {
      return true;
    }
  }
  return false;
}

void updateSliderPositions() {
  s1.setSliderPosition(sliderValue[mode][0]);
  s1.getSliderPosition();
  s2.setSliderPosition(sliderValue[mode][1]);
  s2.getSliderPosition();
  s3.setSliderPosition(sliderValue[mode][2]);
  s3.getSliderPosition();
  s4.setSliderPosition(sliderValue[mode][3]);
  s4.getSliderPosition();
  s5.setSliderPosition(sliderValue[mode][4]);
  s5.getSliderPosition();

}

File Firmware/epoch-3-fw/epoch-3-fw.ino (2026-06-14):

/**
 Epoch 3 Project - A 10-channel haptic field emitter
 with touch screen by Mark J. Koch.
        https://www.patreon.com/maehem


  Choose RPi Pico2 as target processor in Arduino

 * * * * * * * * * * * * * * * * * * * * * * * * * * * * * * * * * * *

  MIT license
 ********************************************************************
 
 */
#include <Wire.h>
#include <Adafruit_PWMServoDriver.h>
#include <SPI.h>
#include <TFT_eSPI.h>
#include "glyphs.h"

// Width and height of sprite
#define WIDTH  128
#define HEIGHT 88

#define TOUCH_X_MIN 220
#define TOUCH_Y_MIN 3920
#define TOUCH_X_MAX 3800
#define TOUCH_Y_MAX 240


// default address 0x40
Adafruit_PWMServoDriver pwm = Adafruit_PWMServoDriver();  // PWM functions
TFT_eSPI tft = TFT_eSPI();                                // Screen and touch related functions
TFT_eSprite spr = TFT_eSprite(&tft);                      // Declare Sprite object "spr" with pointer to "tft" object

boolean wastouched = false;
boolean istouched = false;
uint32_t scanTime = millis();

void setup() {
  Serial.begin(115200);
  Serial.println("\n\nEpoch 3 Startup...");
  spr.setColorDepth(1);

  pwmInit();

  tft.init();
  tft.setRotation(0);  // Epoch 3 is portriat mode.

  // Run Touch Calibrate TFT-eSPI example for these values.
  uint16_t calData[5] = { 260, 3429, 247, 3635, 4 };
  tft.setTouch(calData);

  Serial.println("\nsplash");
  showSplashScreen();
  delay(1000);
  
  Serial.println("\nmainpage");
  mainPageInit();
}

void loop() {
  mainPageLoop();
  pwmLoop();
}

void showSplashScreen() {
  spr.createSprite(WIDTH, HEIGHT);
  spr.setBitmapColor(0x9110, 0x0000);
  tft.fillScreen(TFT_BLACK);
  tft.setTextColor(0x9110);
  tft.drawCentreString("Epoch 3",tft.width()/2, tft.height()/2-88, 4);
  // push the image - only need to do this once.
  spr.pushImage(0, 0, WIDTH, HEIGHT, (uint16_t *)logo);
  // create a palette with the defined colors and push it.
  spr.pushSprite(tft.width() / 2 - WIDTH / 2, tft.height() / 2 - HEIGHT / 2);
}

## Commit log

2026-02-19 Add rev.A of Epoch3 PCB
    [main-board.kicad_pcb, main-board.kicad_sch]
2026-02-19 Save setup template for TFT Driver
2026-02-20 Non-populate 3-pin header.
    [main-board.kicad_pcb, main-board.kicad_sch]
2026-02-20 Update date field.
    [main-board.kicad_sch]
2026-02-20 Add Schematic for Rev.A PCB
2026-02-20 Add BOM
    [epoch-3-main-board-rev-a-BOM.ods]
2026-02-22 Add simple tests for PWM and TFT with Touch.
2026-03-15 Add wave calculations chart.
    [epoch3-waves.ods]
2026-03-15 Add red-line notes.
    [main-board.kicad_sch]
2026-04-01 Create larger motor PCB for 12mm motor.
    [motor-board-12mm.kicad_pcb, motor-board-12mm.kicad_sch]
2026-04-29 Change cap value.
    [motor-board-12mm.kicad_sch]
2026-06-14 Add trimTime flag and toggle button for trim mode.
2026-06-14 Redesigned alt modes and added 'trim' time mode.
    [pwmStuff.ino]
